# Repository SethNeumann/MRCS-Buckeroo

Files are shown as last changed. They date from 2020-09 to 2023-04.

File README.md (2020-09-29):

MRCS-Buckeroo

## License: Creative Commons Attribution-NonCommercial-ShareAlike

MRCS-Buckeroo

Model Railroad projects often require one or more power supplies for lighting and electronics powered from an 
auxilliary powr bus, usually 12VDC or a local "wall wart" power supply.  Commercial bucking supplies based on
LM 2596 or boosters based on XL6009 offere an inexpensive basis for developing any voltage from 3-35 volts with 
an input of 3-25 volts by choosing and adjusting an appropriate module.  

The Buckeroo has a 2.1 x 5.5 mm barrel connector and a 3.5mm screw terminal for input and 12 x 0.100 terminals 
power and ground out.  You may also use it as a power distribution block for layout bus power or a wall wart 
without further conversion by omitting the converter and jumpering around its pads.

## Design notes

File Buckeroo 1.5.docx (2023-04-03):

“Buckeroo”

Revision 0.3 02/17/2023

Seth Neumann, seth@modelrailroadcontrolsystems.com

Introduction

This document describes the Buckeroo power distribution board and how to assemble and install it.

Revision History

V0.1 – first pass – December 6, 2020

V 0.2 – adjusted connector designations, fixed typos December 7, 2020

V 0.3 – cover updates in rev 1.3-1.5

Table of Contents

Table of Figures

Table of Tables

# 1 Introduction

We often need to distribute power and ground for various devices under the layout and various power distribution boards have been offered over the years. This one fits our standard 7CM Tyco track (“Din Rail”) but can also be mounted using #6 screws and standoffs.

The Buckeroo provides connectors to distribute up to 12 pairs of positive voltage and ground. Pads are provided for a bucking or boosting converter to develop any voltage from about 3 - 30 volts. We assume you are running a 12V auxiliary power bus around your layout for switch machines, control panels and miscellaneous animations. The buckeroo is an easy way to derive other voltages (usually 5 or 3.3) as needed without having to run long busses from centralized power supplies with resultant I2R losses.

This revision (February 2023) supports pads for 2 more bucker and buck/boost converter footprints. As time goes on we will release further versions to support the then-available converter modules. Additionally, pads are provided for a simple linear regulator using TO-220 footprint regulators in the 78xx series, for those who prefer linear regulators.

Features:

- Takes power from either a 2.1 mm barrel jack or a 3.5mm two position screw terminal (I use this to take power from my 12 volt auxiliary bus and break it out for clusters of devices under the layout at whatever DC voltage is required).
- Connector pads provide up to 12 connections on 0.100 centers for +V and -V (Ground.) If you are assembling your own board and need less connections, you can use connectors with fewer positions.
- Pads for an LM2596 bucking (down) converter or an XL6009E boost (up) converter.
- Pads for MH340 mini bucking converters
- Pads for 6009 based buck/boost converters
- Pads for LM78xx regulators and associated capacitors
- Pads for 0.100 jumpers to be used if no buck or boost is required (distribution from layout aux power bus or from a wall wart of appropriate voltage).
- All components are through-hole technology for ease of assembly and repair.

Output connection pads and converter bypass jumpers are on 0.100” centers. This provides for a wide range of interconnect options and components. Connection options include screw terminal blocks, header pin connectors (male and female), right angle headers, and direct soldered wires.

Schematic, circuit board layouts and CAD files are available on the product page on our website and on my GitHub page https://github.com/SethNeumann.

# 2 Identification and Information

## 2.1. Board Layout

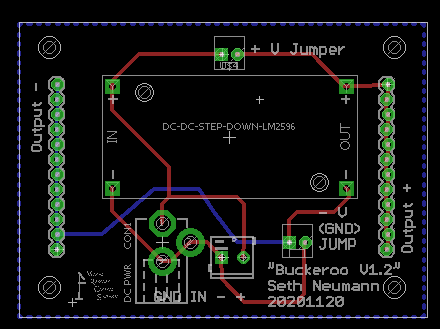
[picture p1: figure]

Figure 1 - Rev 1.2 Board Layout

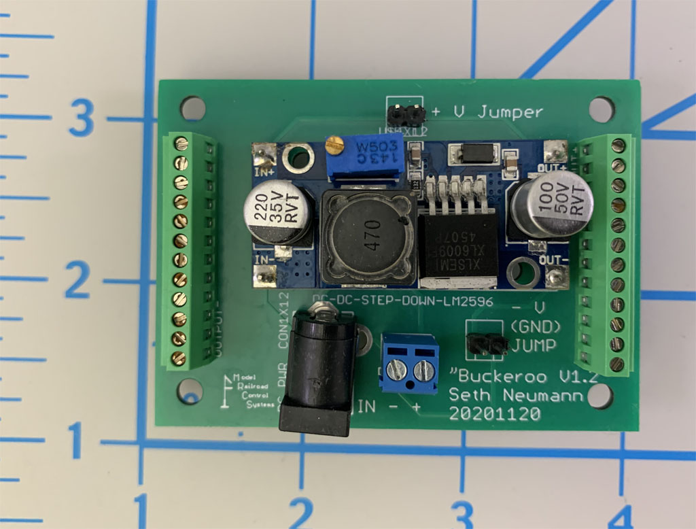
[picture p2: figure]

Figure 2 – Rev 1.2 Board (with boost converter) Top View

This board is sold as a single unit, assembled, and tested or as bare board, panel of 2. If you are interested in alternate connectors, alternate converters, large quantities, or custom modifications please contact us at sales@modelrailroadcontrolsystems.com

## 2.2. Bill of Materials

Table 1- Bill of Materials Rev 1.1

[update with various configurations and current prices]

Note these costs are correct as of December 2020 but will change over time. I’ve given Jameco (www.jameco.com) part numbers and prices where available and used Amazon, eBay and various Asian suppliers. These prices are for 10s which is lowest quantity that’s economical. For the bypass pins (CON3, CON4) I use 0.100 male headers. These can be purchased at about $0.01 per pin in breakaway strips of 40. Search the suppliers above and buy a pack of 10, which should keep you supplied for a few projects. Your cost per buckeroo (obviously you will have at least 2 as the board is a panel of 2) will vary from about $4.00 for a straight distribution block to $6.00 with a boost converter, depending on how you buy.

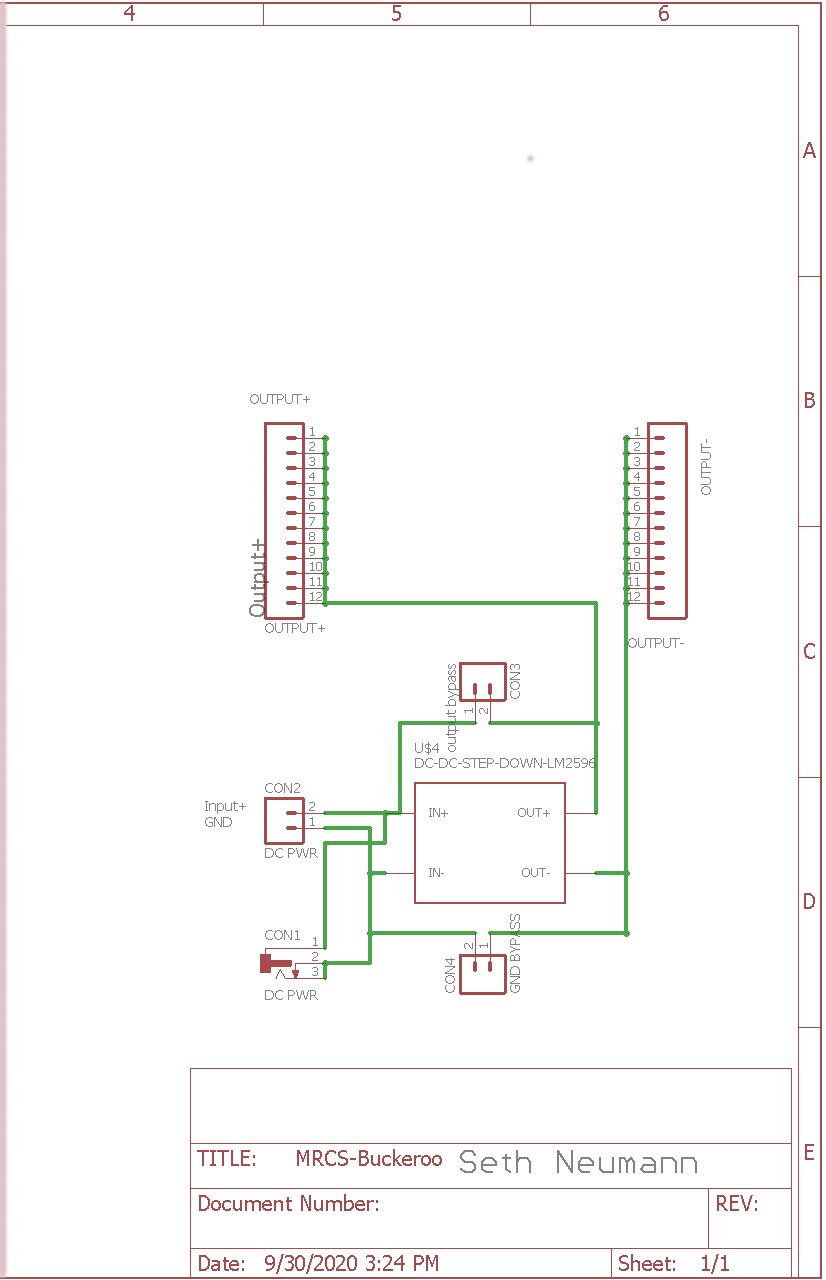
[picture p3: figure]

Figure 3 - Rev 1.2 Schematic

# 3 Options

## 3.1. Connectors

- The distribution and bypass connectors are on 0.100 centers (staggered slightly to hold the connectors in place during assembly). While our standard connector is the 0.100 screw terminal, you may substitute any 0.100 connector you prefer. If you are ordering an assembled and tested unit from MRCS and you would prefer a different connector, please contact us at sales@modelrailroadcontrolsystems.com and indicate your preference and we’ll provide a quotation.
- The Buckeroo has input pads for both a 2.1 mm barrel connector (usually used with a wall wart type power supply) and a 2 position 3.5mm screw terminal block. Either one or both may be used (for example if you want to daisy chain two Buckeroos together to get more outputs or two provide 2 voltages – one converter per Buckie).
- If you are using a buck or boost converter, you don’t need the bypass jumpers and may omit them. Both the buck and boost converters have an internal connection between their INPUT- and OUTPUT – terminals.
- If you are looking to save a few cents, solder jumpers of 22 Ga wire in place of the bypass jumpers (if used) and only equip the number of output screw terminals required. The 0.100 screw terminals cost ~$0.10 per terminal and are available in 2,3,4,6,8 and 12 pin configurations. If you only have (say) 4 devices needing power, you don’t need to stuff all 12 outputs.

## 3.2. Alternate Buck and boost converters

- MH340. This is a small converter, good for w.ww watts and suitable for small loads (perhaps you need ao supply 1,5 V for a vintage structure with grain of wheat bulbs).
- NNNN buck boost converter. Takes 12V in and produces from 3.3 to 33 volts out. Note that these are not well protected against setting the output voltage too high so use care in setting the high end of output volts. The failure mode is the board stops working, it does NOT short the input to the output.
- LM78xx linear regulators. Use the appropriate regulator (ex: 7805 produces 5V). Pads are provided for typical values of input and output filter capacitors (can also be added for straight distribution boards to decouple local loads). This design mounts the device vertically and relies on its integrated heat sink (bare metal tab) but you can add a heat sink for additional capacity. If these devices get to warm they “fold back” and drop the output votage/current to protect themselves.
- Most of these modules are 3 terminal devices (that is input, output and common ground) but 4 terminal (isolated input and output negative) are out there and some of the documentation isn’t the best, so check and set the bypass jumpers accordingly.

[insert table here]

Regulator | Input V | Output Voltage | Output Current | Watts
2596 | 12
6009 boost | 12
6009 buck/boost | 12 | 5
6009 buck/boost | 12 | 24
LM7809 | 12 | 9
LM7805 | 12 | 5

# 4 Assembly

All of the components are through-hole technology with wire leads. The general rule is install the lowest components first, working towards components that are higher off the board. This enables you to support the low components as you solder them. The suggested order assumes you are using both input connectors, screw terminals for the outputs and male headers for the bypass jumpers. If you choose to use different connectors, check the heights, and vary the build order accordingly.

[ ] Male Headers

[ ] install the bypass jumpers, CON3, CON4, if used. Hint – use a spare board as a jig to hold them in place as you solder

[ ] If using a buck/boost converter, break off 4 header pins and solder them onto the bottom of the IN-, IN+, OUT- and OUT+ holes with the long side down. Use a bare board as jig. Solder from the top. You could also use pin and socket combinations or bare wire

[ ] Screw Terminals

[ ] Install the OUTPUT- and OUTPUT+ screw terminals. . If you need less than 12 connections, feel free to use a screw terminal with fewer positions. These are available in many sizes from 2 to 12 positions

[ ] Install the 3.5mm input connector (if used)

[ ] Small ceramic filter caps, if used

Install after the screw terminals as you should leave about 1/32” of lead above the board to avoid breaking the leads internally

[ ] Barrel Jack

[ ] Install the barrel jack, if used

[ ] Electrolytic filter capacitor, if used

These usually stad up about 10-15 mm, compare with barrel jack to determine sequence

[ ] Install the Buck/Boost converter, if used. I used 0.100 header pins for the input and output pins in the corners. You could also use pin and socket combinations or bare wire.

[ ] slip the “Berg Jumpers” onto the bypass pins CON3, CON4 if not using a converter or regulator.

# 5 Testing

Testing your Buckeroo is quick and simple:

1. Using a voltmeter set to resistance (or continuity if has a beeper) put one lead on the input screw terminal – and check for continuity with the -V bypass jumper, do the same with + and the +V jumper.
2. Check from the other side of the bypass jumper to each of the screw terminals in use. I find I sometimes miss a pad when soldering these.
3. If not using a bucker/booster, connect your input voltage and install the jumpers and check that you see the same voltage on the outputs
4. If using a bucker/booster or a regulator, apply power to the input and connect your meter across OUTPUT + and OUTPUT - (clip leads will be handy). Adjust the output voltage to your desired voltage by turning the small screw on blue pot counterclockwise. It’s a 20-turn pot, so it may take a while to see anything happen.

# 6 Installation and Connections

## 6.1 Power Connections

Note that 24 Ga wire can handle up to 0.6A (600 mA). So, the total current delivered over any conductor should not exceed 600 mA. Also note that the bucking converter can only source 3A, and since most of us buy these from inexpensive suppliers on major commerce and auction sites, it is wise to allow a little margin of safety.

If in doubt, contact us! sales@modelrailroadcontrolsystem.com

Page 2 www.modelrailroadcontrolsystems.com December 7, 2020

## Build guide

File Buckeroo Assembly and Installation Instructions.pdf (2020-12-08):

# “Buckeroo”

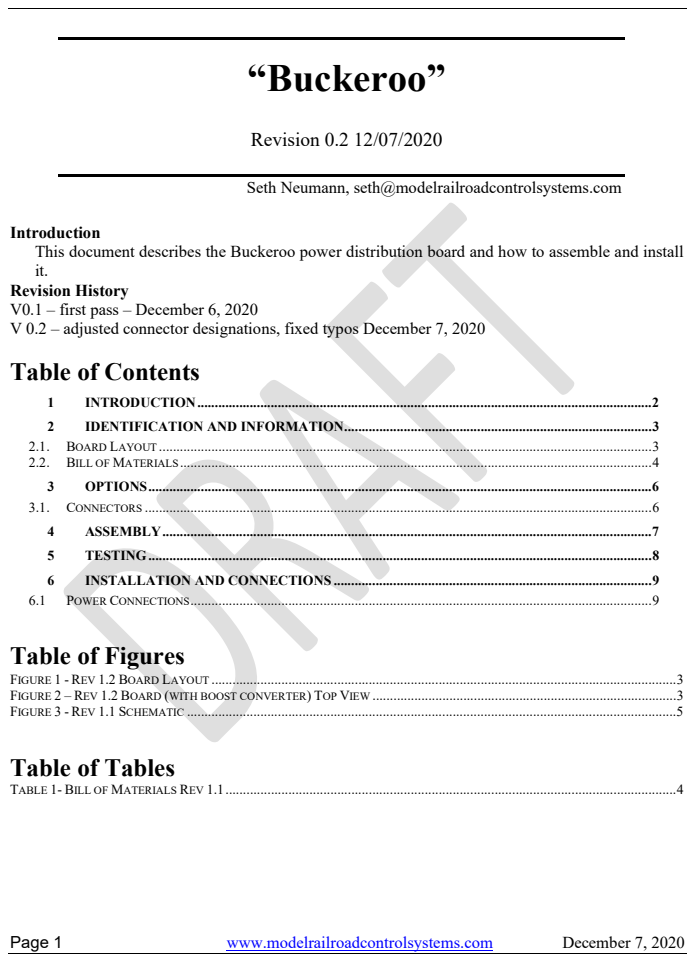
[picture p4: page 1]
Page 1; www.modelrailroadcontrolsystems.com; December 7, 2020; Revision 0.2 12/07/2020

Seth Neumann, seth@modelrailroadcontrolsystems.com

Introduction
This document describes the Buckeroo power distribution board and how to assemble and install
Revision History
V0.1 – first pass – December 6, 2020
V 0.2 – adjusted connector designations, fixed typos December 7, 2020
Table of Contents

1 INTRODUCTION .................................................................................................................................. 2
2 IDENTIFICATION AND INFORMATION ........................................................................................ 3
2.1. BOARD LAYOUT ............................................................................................................................................. 3
2.2. BILL OF MATERIALS ....................................................................................................................................... 4
3 OPTIONS ................................................................................................................................................ 6
3.1. CONNECTORS ................................................................................................................................................. 6
4 ASSEMBLY ............................................................................................................................................ 7
5 TESTING ................................................................................................................................................ 8
6 INSTALLATION AND CONNECTIONS ........................................................................................... 9
6.1 POWER CONNECTIONS .................................................................................................................................... 9
Table of Figures

FIGURE 1 - REV 1.2 BOARD LAYOUT ..................................................................................................................................... 3
FIGURE 2 – REV 1.2 BOARD (WITH BOOST CONVERTER) TOP VIEW ....................................................................................... 3
FIGURE 3 - REV 1.1 SCHEMATIC ............................................................................................................................................ 5
Table of Tables
TABLE 1- BILL OF MATERIALS REV 1.1 ................................................................................................................................. 4

Page 2 | www.modelrailroadcontrolsystems.com | December 7, 2020

### 1 INTRODUCTION

The Buckeroo provides connectors to distribute up to 12 pairs of positive voltage and ground. Pads are provided for a bucking or boosting converter to develop any voltage from about 3 - 30 volts.

We often need to distribute power and ground for various devices under the layout and various power distribution boards have been offered over the years. This one fits our standard 7CM Tyco track (“Din Rail”) but can also be mounted using #6 screws and standoffs.

Features:

- Takes power from either a 2.1 mm barrel jack or a 3.5mm two position screw terminal (I use this to take power from my 12 volt auxiliary bus and break it out for clusters of devices under the layout at whatever DC voltage is required).
- Connector pads provide up to 12 connections on 0.100 centers for +V and -V (Ground.) If you are assembling your own board and need less connections, you can use connectors with fewer positions.
- Pads for an LM2596 bucking (down) converter or an XL6009E boost (up) converter.
- Pads for 0.100 jumpers to be used if no buck or boost is required (distribution from layout aux power bus or from a wall wart of appropriate voltage).
- All components are through-hole technology for ease of assembly and repair.

Output connection pads and converter bypass jumpers are on 0.100” centers. This provides for a wide range of interconnect options and components. Connection options include screw terminal blocks, header pin connectors (male and female), right angle headers, and direct soldered wires.

Schematic, circuit board layouts and CAD files are available on the product page on our website and on my GitHub page https://github.com/SethNeumann.

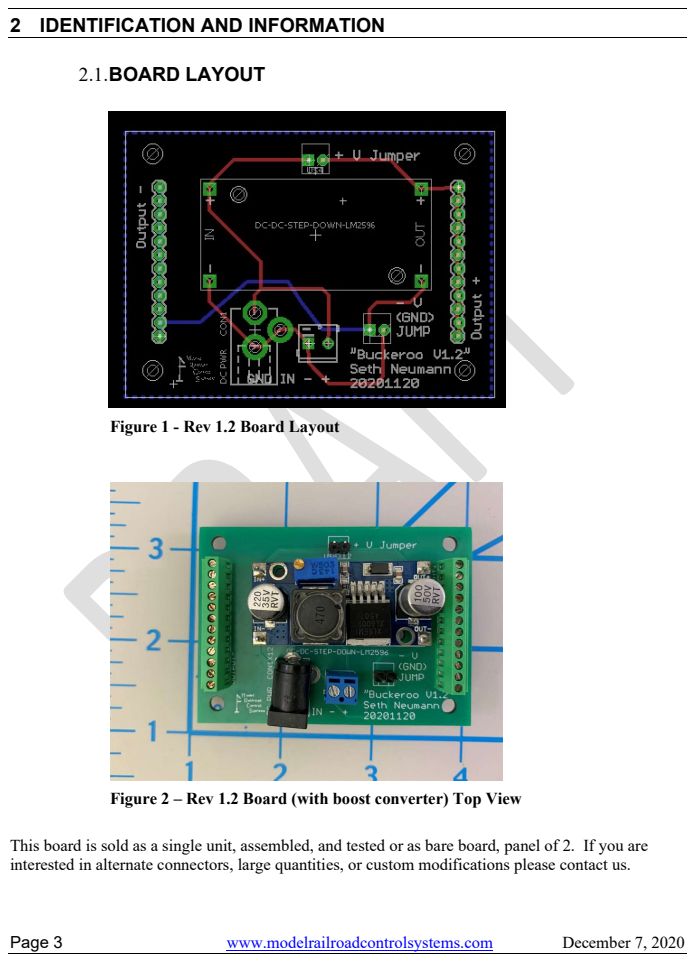
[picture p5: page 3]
Page 3; www.modelrailroadcontrolsystems.com; December 7, 2020; 2.1.BOARD LAYOUT

2 IDENTIFICATION AND INFORMATION

Figure 1 - Rev 1.2 Board Layout

Figure 2 – Rev 1.2 Board (with boost converter) Top View

This board is sold as a single unit, assembled, and tested or as bare board, panel of 2. If you are
interested in alternate connectors, large quantities, or custom modifications please contact us.

Page 4 | www.modelrailroadcontrolsystems.com | December 7, 2020

2.2.BILL OF MATERIALS

Qty | Value | Package | Parts | Description | Jameco | _1 | Asian/eBay/AMZNExtd
1 DC PWR | DCJ0202 | CON1 | DC POWER JACK | 101178 $ 0.50 $ | 0.08 $ 0.08
1 DC PWR | SCREWTERMINAL-3.5MM-2_LOCK | CON2 | PHOENIX CONNECTOR | 2094506 $ 0.35 | $ 0.35
1 DC-DC-STEP-DOWN-LM2596 | DC-DC-STEP-DOWN-LM2596 | U$4 | DC/DC Step-Down Regulator based on LM2596-ADJ chip | $ | 1.25 $ 1.25
1 DC-DC-STEP-STEP UP-XL6009 | DC-DC-STEP-DOWN-LM2596 | U$4 | DC/DC Step-Up Regulator based on XL6009 chip | $ | 2.00 $ 2.00
2 BYPASS | MOLEX-1X2_LOCK | CON3, CON4 | PHOENIX CONNECTOR | $ | 0.01 $ 0.02
2 OUTPUT+ | 1X12_LOCK | OUTPUT+, OUTPUT - Screw Terminal | $ | 0.80 $ 1.60
2 | 1x2 | Berg jumper for bypass | 19141 | $ | 0.13 $ 0.26
1 Printed Circuit Board | $ | 2.50 | $2.50

Table 1- Bill of Materials Rev 1.1

Note these costs are correct as of December 2020 but may change over time. I’ve given Jameco (www.jameco.com) part numbers and prices where available and used Amazon, eBay and various Asian suppliers. These prices are for 10s which is lowest quantity that’s economical. For the bypass pins (CON3, CON4) I use 0.100 male headers. These can be purchased at about $0.01 per pin in breakaway strips of 40. Search the suppliers above and buy a pack of 10, which should keep you for a few projects. Your cost per buckeroo (obviously you will have at least 2 as the board is a panel of 2) will vary from about $4.00 for a straight distribution block to $6.00 with a boost converter, depending on how you buy.

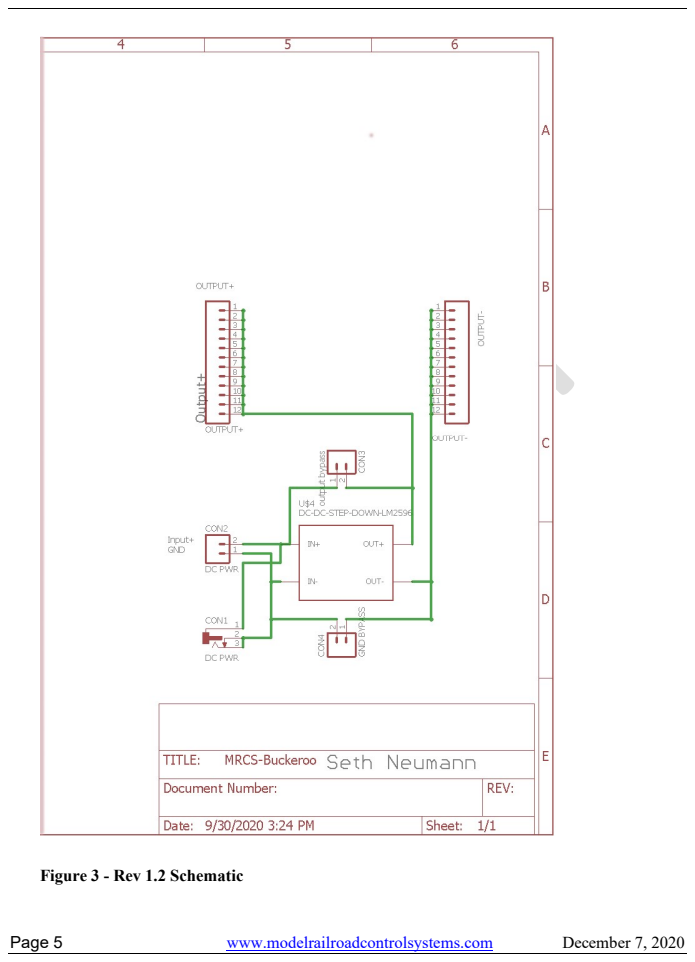
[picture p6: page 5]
Page 5; www.modelrailroadcontrolsystems.com; December 7, 2020

Figure 3 - Rev 1.2 Schematic

Page 6 | www.modelrailroadcontrolsystems.com | December 7, 2020

### 3 OPTIONS

3.1.CONNECTORS

- The distribution and bypass connectors are on 0.100 centers (staggered slightly to hold the connectors in place during assembly). While our standard connector is the 0.100 screw terminal, you may substitute any 0.100 connector you prefer. If you are ordering an assembled and tested unit from MRCS and you would prefer a different connector, please contact us at sales@modelrailroadcontrolsystems.com and indicate your preference and we’ll provide a quotation.
- The Buckeroo has input pads for both a 2.1 mm barrel connector (usually used with a wall wart type power supply) and a 2 position 3.5mm screw terminal block. Either one or both may be used (for example if you want to daisy chain two Buckeroos together to get more outputs or two provide 2 voltages – one converter per Buckie).
- If you are using a buck or boost converter, you don’t need the bypass jumpers and may omit them. Both the buck and boost converters have an internal connection between their INPUT-and OUTPUT – terminals.
- If you are looking to save a few cents, solder jumpers of 22 Ga wire in place of the bypass jumpers (if used) and only equip the number of output screw terminals required. The 0.100 screw terminals cost ~$0.10 per terminal and are available in 2,3,4,6,8 and 12 pin configurations. If you only have (say) 4 devices needing power, you don’t need to stuff all 12 outputs.

Page 7 | www.modelrailroadcontrolsystems.com | December 7, 2020

### 4 ASSEMBLY

All of the components are through-hole technology with wire leads. The general rule is installing the lowest components first, working towards components that are higher off the board. This enables you to support the low components as you solder them. The suggested order assumes you are using both input connectors, screw terminals for the outputs and male headers for the bypass jumpers. If you choose to use different connectors, check the heights, and vary the build order accordingly.

[ ] Male Headers

[ ] install the bypass jumpers, CON3, CON4, if used. Hint – use a spare board as a jig to hold them in place as you solder
[ ] If using a buck/boost converter, break off 4 header pins and solder them onto the bottom of the IN-, IN+, OUT- and OUT+ holes with the long side down. Use a bare board as jig. Solder from the top. You could also use pin and socket combinations or bare wire

[ ] Screw Terminals
[ ] Install the OUTPUT- and OUTPUT+ screw terminals. . If you need less than 12 connections, feel free to use a screw terminal with fewer positions. These are available in many sizes from 2 to 12 positions
[ ] Install the 3.5mm input connector (if used)

[ ] Barrel Jack
[ ] Install the barrel jack, if used

[ ] Install the Buck/Boost converter, if used. I used 0.100 header pins for the input and output pins in the corners. You could also use pin and socket combinations or bare wire.

[ ] slip the “Berg Jumpers” onto the bypass pins CON3, CON4 if not using a bucker or booster.

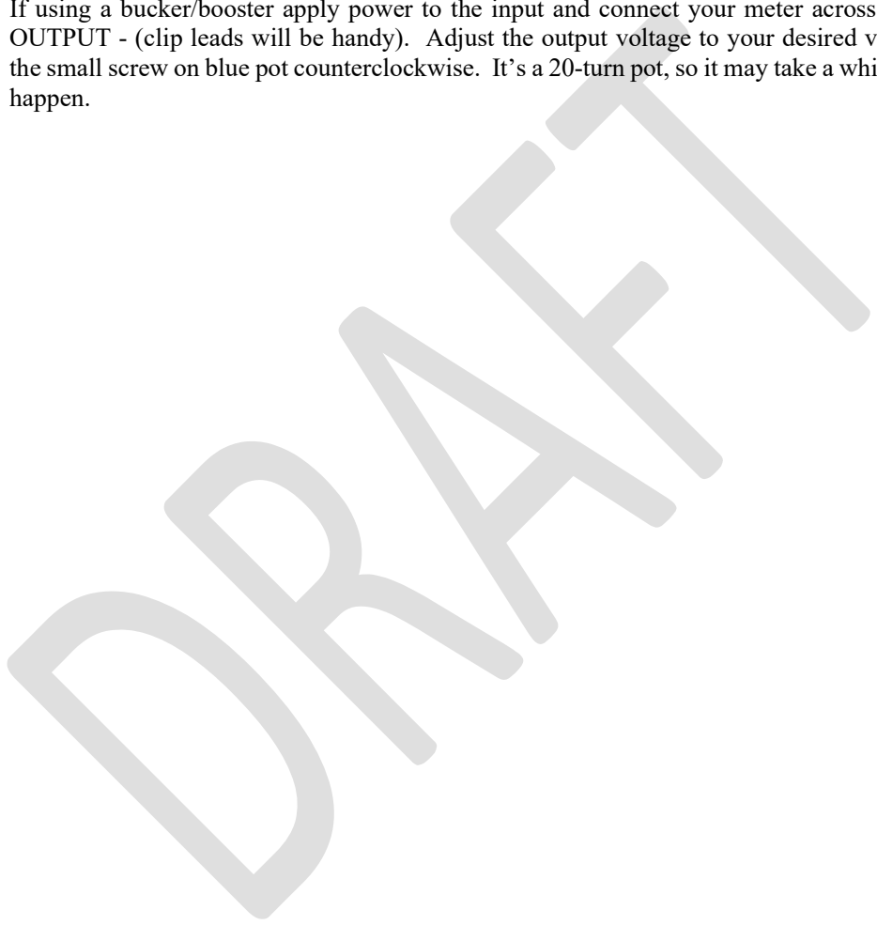
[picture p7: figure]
happen.

Page 8 | www.modelrailroadcontrolsystems.com | December 7, 2020

### 5 TESTING

Testing your Buckeroo is quick and simple:
1. Using a voltmeter set to resistance (or continuity if has a beeper) put one lead on the input screw terminal – and check for continuity with the -V bypass jumper, do the same with + and the +V jumper.
2. Check from the other side of the bypass jumper to each of the screw terminals in use. I find I sometimes miss a pad when soldering these.
3. If not using a bucker/booster, connect your input voltage and install the jumpers and check that you see the same voltage on the outputs
4. If using a bucker/booster apply power to the input and connect your meter across OUTPUT + and OUTPUT - (clip leads will be handy). Adjust the output voltage to your desired voltage by turning the small screw on blue pot counterclockwise. It’s a 20-turn pot, so it may take a while to see anything

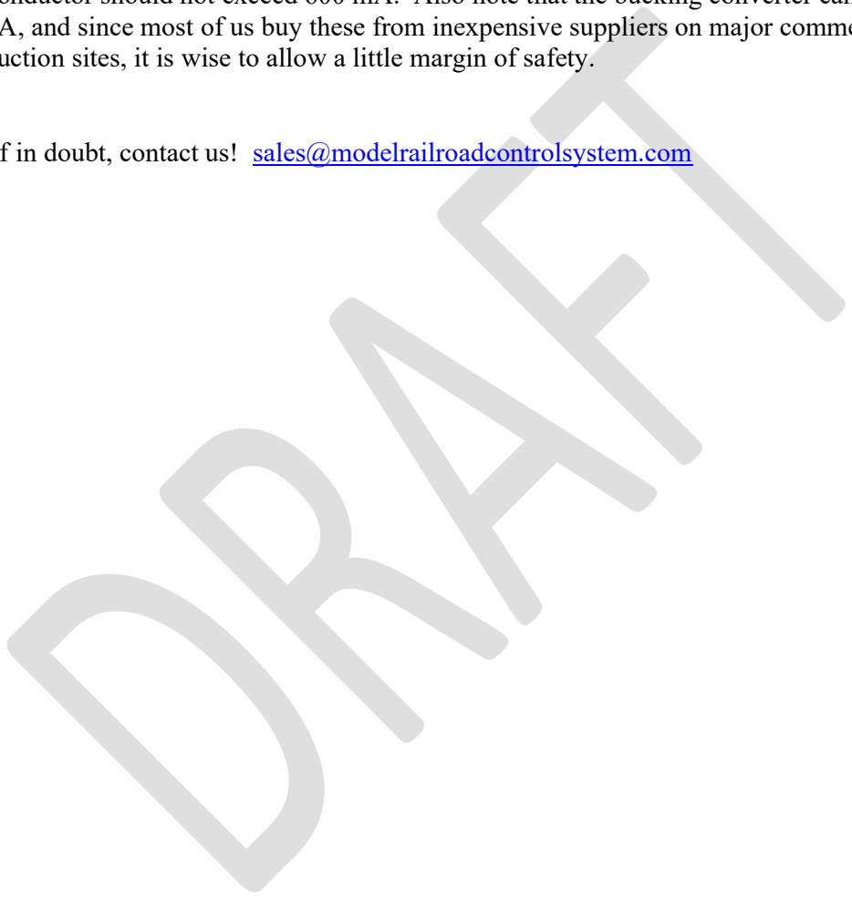
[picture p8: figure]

Page 9 | www.modelrailroadcontrolsystems.com | December 7, 2020

### 6 INSTALLATION AND CONNECTIONS

### 6.1 POWER CONNECTIONS

Note that 24 Ga wire can handle up to 0.6A (600 mA). So, the total current delivered over any conductor should not exceed 600 mA. Also note that the bucking converter can only source 3A, and since most of us buy these from inexpensive suppliers on major commerce and auction sites, it is wise to allow a little margin of safety.

If in doubt, contact us! sales@modelrailroadcontrolsystem.com

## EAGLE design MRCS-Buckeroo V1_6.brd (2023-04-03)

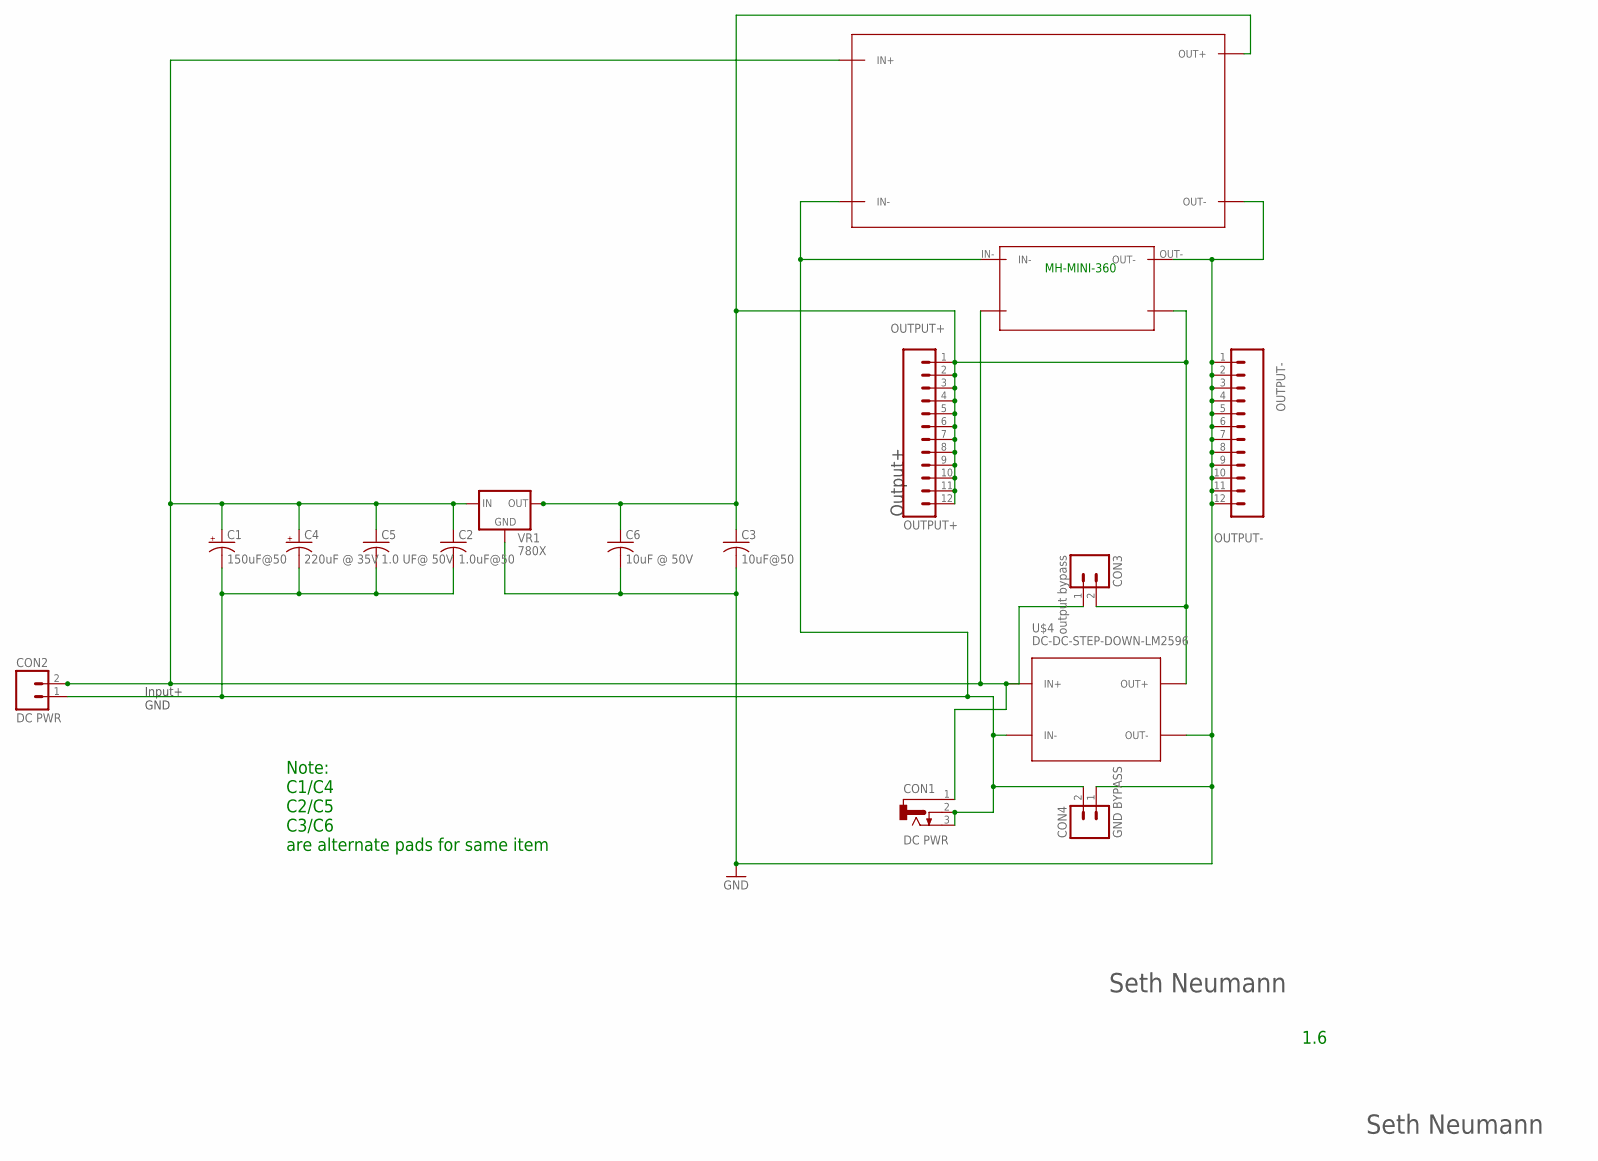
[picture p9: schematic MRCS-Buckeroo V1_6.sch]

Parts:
C1: 150uF@50; E5-10.5
C2: 1.0uF@50; C-PTH-0.100
C3: 10uF@50; C-PTH-0.100
C4: 220uF @ 35V; E2.5-6
C5: 1.0 UF@ 50V; C050-024X044
C6: 10uF @ 50V; C050-024X044
CON1: DC PWR; DCJ0202
CON2: DC PWR; SCREWTERMINAL-3.5MM-2_LOCK
CON3: output bypass; MOLEX-1X2_LOCK
CON4: GND BYPASS; MOLEX-1X2_LOCK
MH-MINI-360: MH-MINI-360
OUTPUT+: OUTPUT+; 1X12_LOCK
OUTPUT-: OUTPUT-; 1X12_LOCK
U$4: DC-DC-STEP-DOWN-LM2596
U$5: XL6009BOARD; XL6009_BOARD
VR1: 780X; TO-220-RA

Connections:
GND: C1.-, C2.2, C3.2, C4.-, C5.2, C6.2, CON1.2, CON1.3, CON2.1 (A), CON4.1 (A), CON4.2 (B), MH-MINI-360.IN-, MH-MINI-360.OUT-, OUTPUT-.1, OUTPUT-.2, OUTPUT-.3, OUTPUT-.4, OUTPUT-.5, OUTPUT-.6, OUTPUT-.7, OUTPUT-.8, OUTPUT-.9, OUTPUT-.10, OUTPUT-.11, OUTPUT-.12, U$4.IN-, U$4.OUT-, U$5.IN-, U$5.OUT-, VR1.GND
INPUT+: C1.+, C2.1, C4.+, C5.1, CON1.1, CON2.2 (B), CON3.1 (A), MH-MINI-360.INN+, U$4.IN+, U$5.IN+, VR1.IN
OUTPUT+: C3.1, C6.1, CON3.2 (B), MH-MINI-360.OUTT+, OUTPUT+.1, OUTPUT+.2, OUTPUT+.3, OUTPUT+.4, OUTPUT+.5, OUTPUT+.6, OUTPUT+.7, OUTPUT+.8, OUTPUT+.9, OUTPUT+.10, OUTPUT+.11, OUTPUT+.12, U$4.OUT+, U$5.OUT+, VR1.OUT

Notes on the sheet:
Output+
Input+ GND
Seth Neumann
MH-MINI-360
1.6
Note: C1/C4 C2/C5 C3/C6 are alternate pads for same item

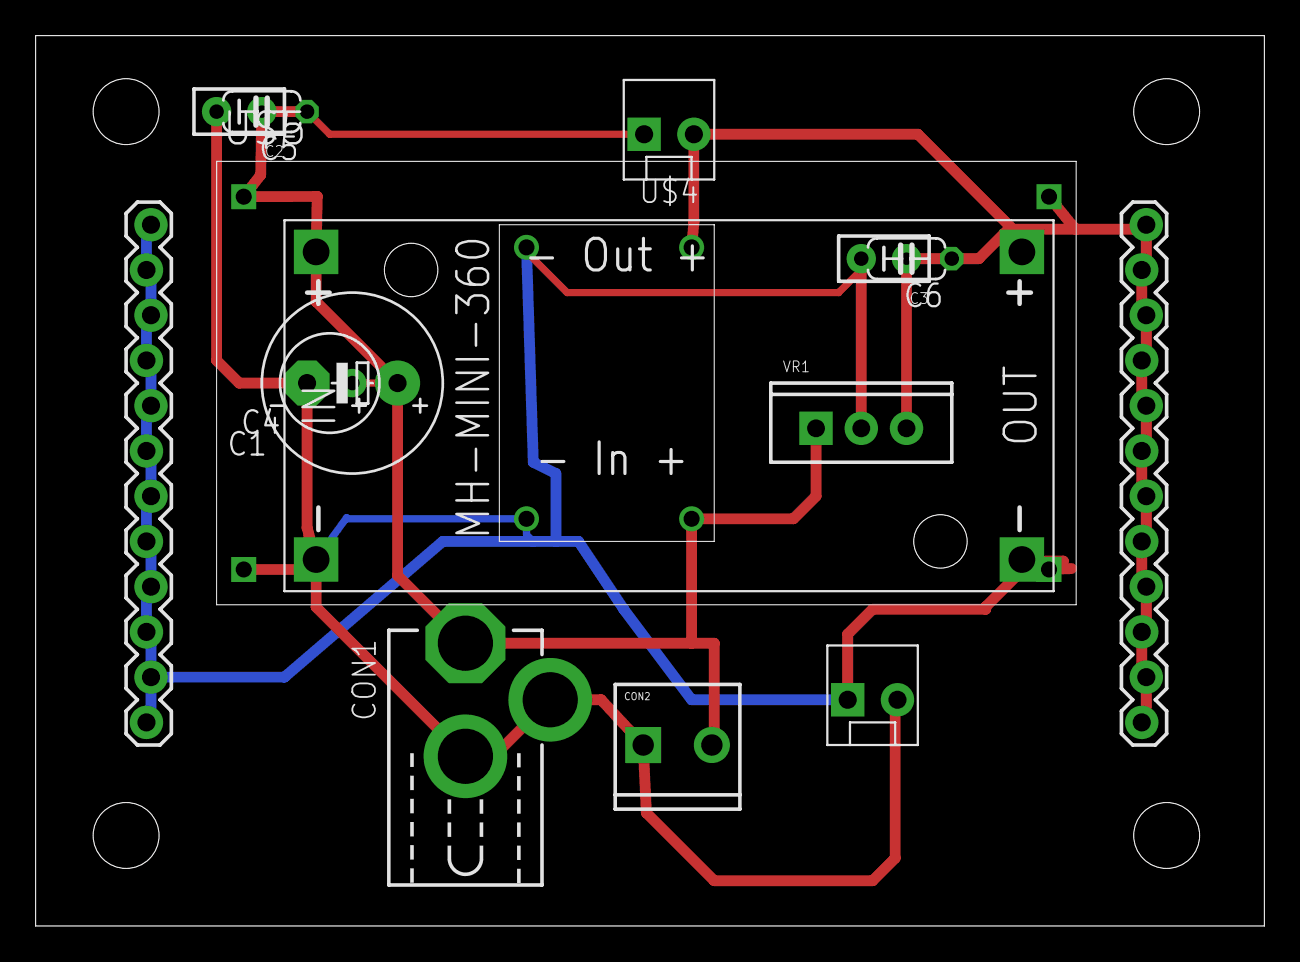
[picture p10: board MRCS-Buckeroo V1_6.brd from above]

Board: 2 copper layers, 69.0 x 50.0 mm, 19 parts (0 on the bottom side), 3 nets.

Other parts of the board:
U$1: CA-PROP65WARNING
U$2: MRCSLOGOTOP
U$3: MRCSLOGOBTM

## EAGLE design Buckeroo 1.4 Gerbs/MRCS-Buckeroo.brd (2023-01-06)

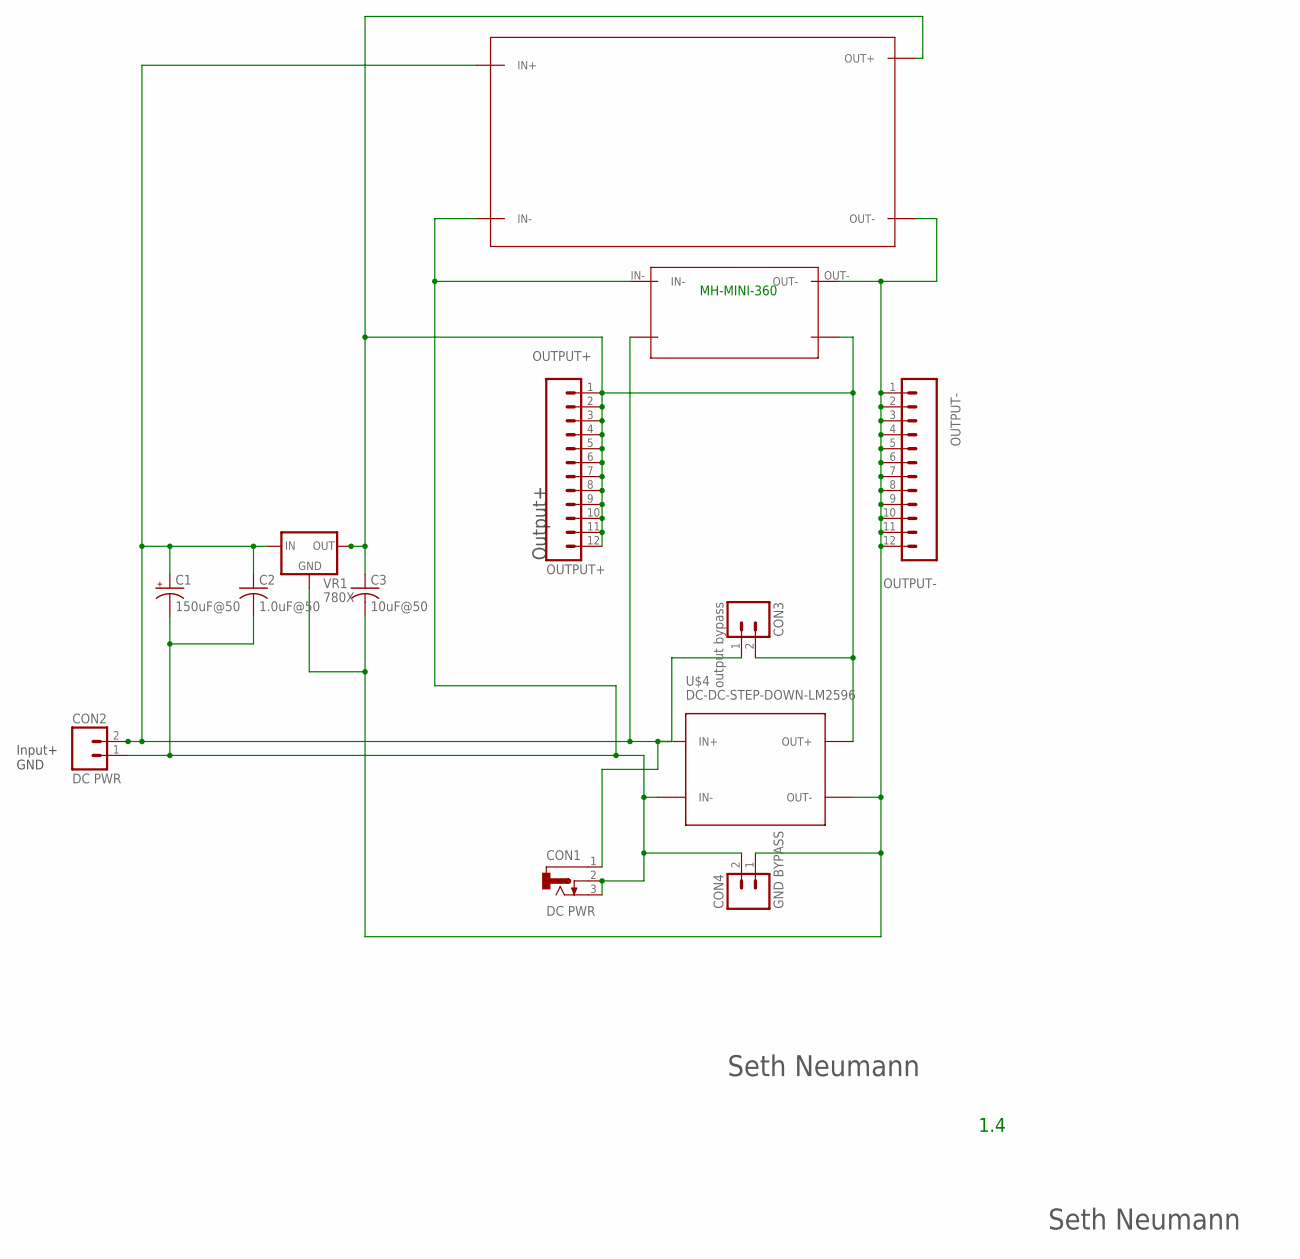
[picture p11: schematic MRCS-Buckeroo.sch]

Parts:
C1: 150uF@50; E5-10.5
C2: 1.0uF@50; C-PTH-0.100
C3: 10uF@50; C-PTH-0.100
CON1: DC PWR; DCJ0202
CON2: DC PWR; SCREWTERMINAL-3.5MM-2_LOCK
CON3: output bypass; MOLEX-1X2_LOCK
CON4: GND BYPASS; MOLEX-1X2_LOCK
MH-MINI-360: MH-MINI-360
OUTPUT+: OUTPUT+; 1X12_LOCK
OUTPUT-: OUTPUT-; 1X12_LOCK
U$4: DC-DC-STEP-DOWN-LM2596
U$5: XL6009BOARD; XL6009_BOARD
VR1: 780X; TO-220-RA

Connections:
GND: C1.-, C2.2, CON1.2, CON1.3, CON2.1 (A), CON4.2 (B), MH-MINI-360.IN-, U$4.IN-, U$5.IN-
INPUT+: C1.+, C2.1, CON1.1, CON2.2 (B), CON3.1 (A), MH-MINI-360.INN+, U$4.IN+, U$5.IN+, VR1.IN
OUTPUT+: C3.1, CON3.2 (B), MH-MINI-360.OUTT+, OUTPUT+.1, OUTPUT+.2, OUTPUT+.3, OUTPUT+.4, OUTPUT+.5, OUTPUT+.6, OUTPUT+.7, OUTPUT+.8, OUTPUT+.9, OUTPUT+.10, OUTPUT+.11, OUTPUT+.12, U$4.OUT+, U$5.OUT+, VR1.OUT
OUTPUT-: C3.2, CON4.1 (A), MH-MINI-360.OUT-, OUTPUT-.1, OUTPUT-.2, OUTPUT-.3, OUTPUT-.4, OUTPUT-.5, OUTPUT-.6, OUTPUT-.7, OUTPUT-.8, OUTPUT-.9, OUTPUT-.10, OUTPUT-.11, OUTPUT-.12, U$4.OUT-, U$5.OUT-, VR1.GND

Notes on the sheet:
Output+
Input+ GND
Seth Neumann
MH-MINI-360
1.4

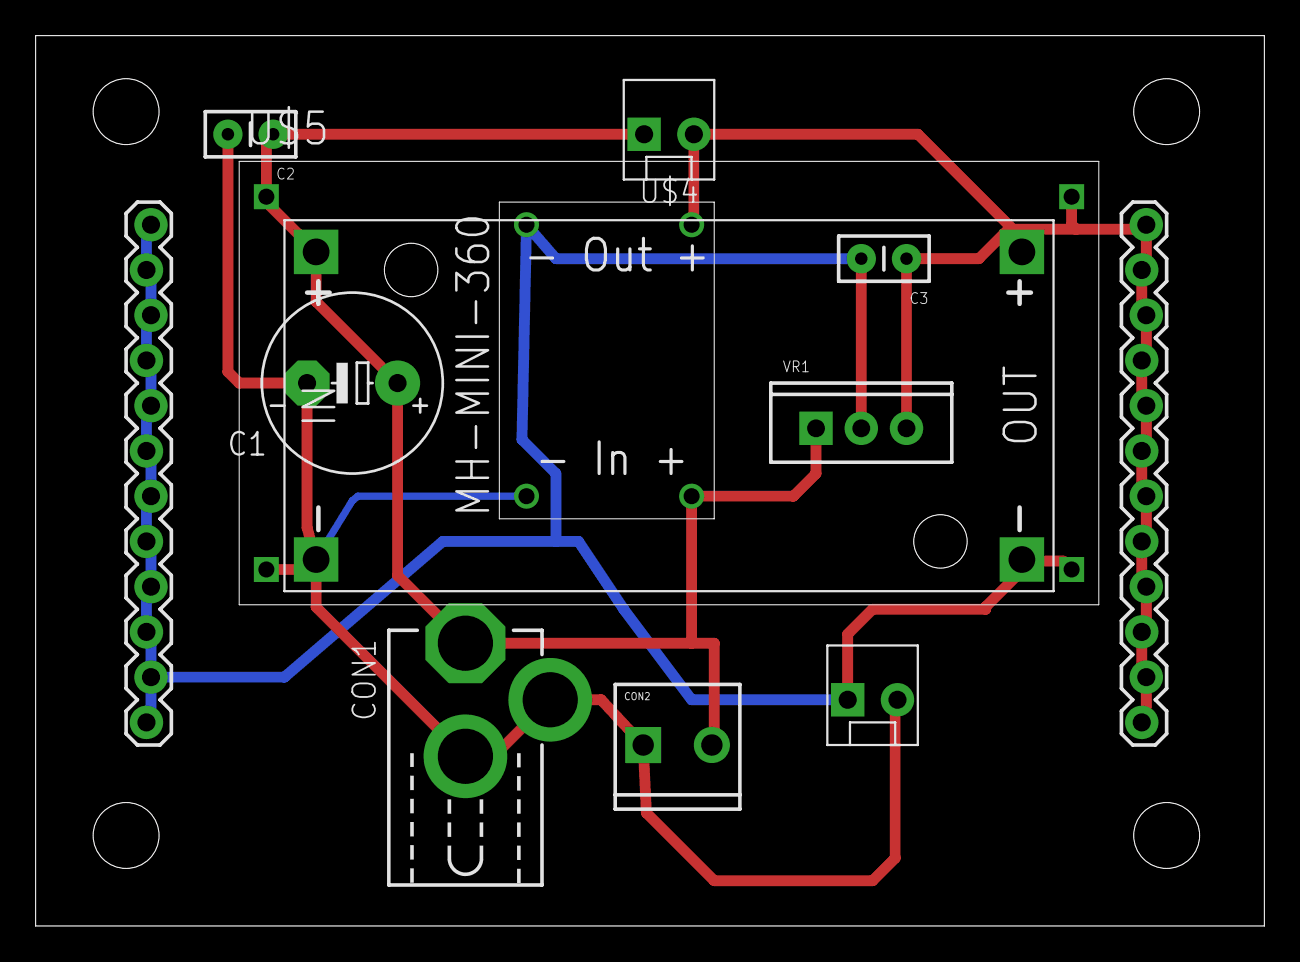
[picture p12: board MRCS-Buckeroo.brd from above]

Board: 2 copper layers, 69.0 x 50.0 mm, 16 parts (0 on the bottom side), 4 nets.

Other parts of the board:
U$1: CA-PROP65WARNING
U$2: MRCSLOGOTOP
U$3: MRCSLOGOBTM

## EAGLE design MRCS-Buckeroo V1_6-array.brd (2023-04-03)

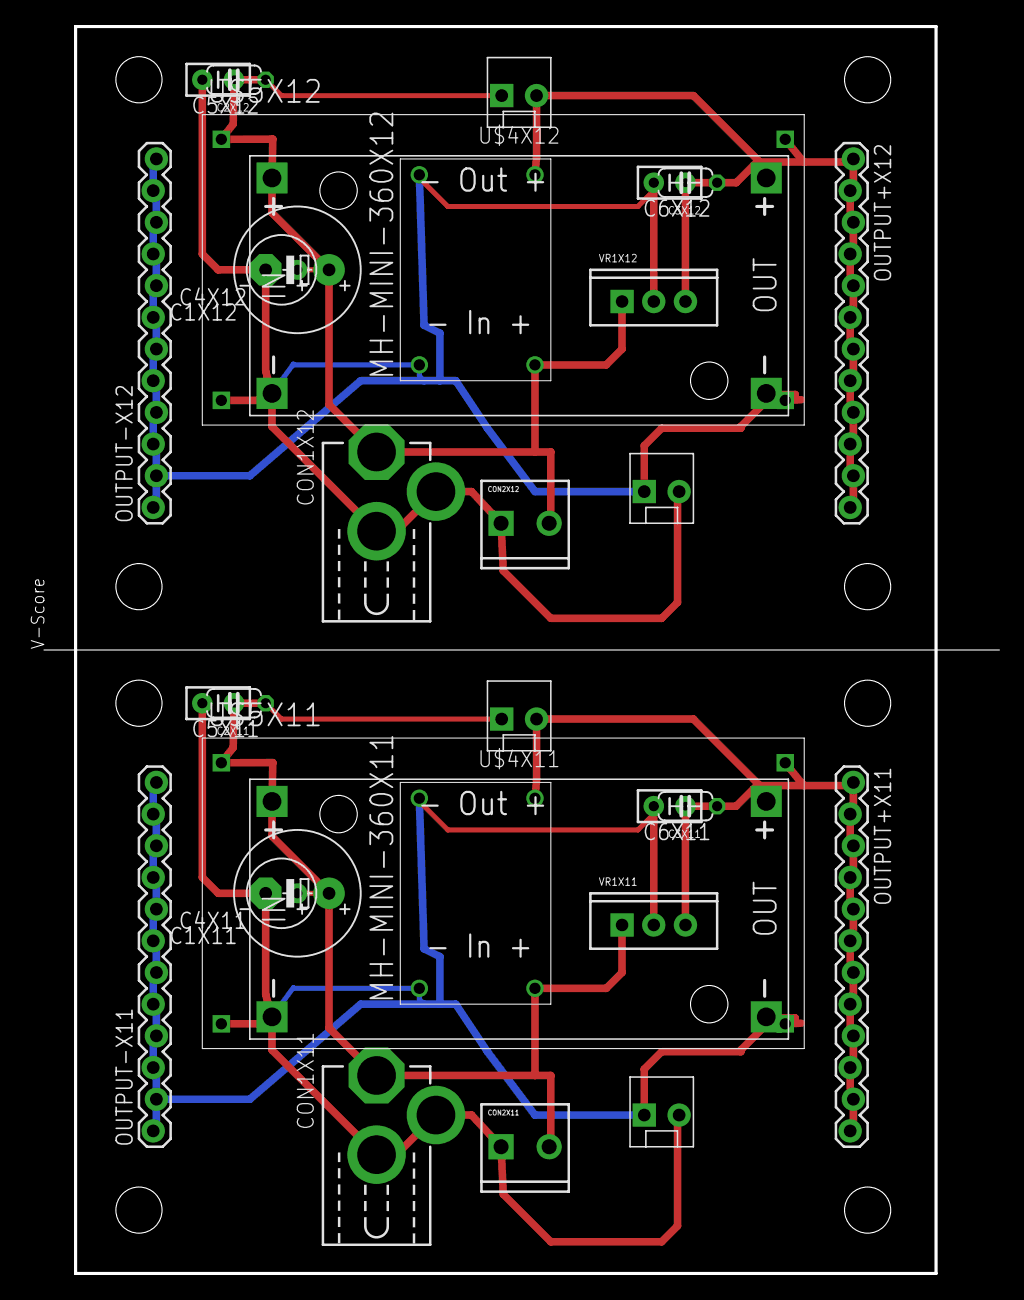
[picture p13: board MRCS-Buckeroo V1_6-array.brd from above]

Board: 2 copper layers, 69.0 x 100.0 mm, 38 parts (0 on the bottom side), 6 nets.

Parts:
C1X11, C1X12: 150uF@50; E5-10.5
C2X11, C2X12: 1.0uF@50; C-PTH-0.100
C3X11, C3X12: 10uF@50; C-PTH-0.100
C4X11, C4X12: 220uF @ 35V; E2.5-6
C5X11, C5X12: 1.0 UF@ 50V; C050-024X044
C6X11, C6X12: 10uF @ 50V; C050-024X044
CON1X11, CON1X12: DC PWR; DCJ0202
CON2X11, CON2X12: DC PWR; SCREWTERMINAL-3.5MM-2_LOCK
CON3X11, CON3X12: output bypass; MOLEX-1X2_LOCK
CON4X11, CON4X12: GND BYPASS; MOLEX-1X2_LOCK
MH-MINI-360X11, MH-MINI-360X12: MH-MINI-360
OUTPUT+X11, OUTPUT+X12: OUTPUT+; 1X12_LOCK
OUTPUT-X11, OUTPUT-X12: OUTPUT-; 1X12_LOCK
U$1X11, U$1X12: CA-PROP65WARNING
U$2X11, U$2X12: MRCSLOGOTOP
U$3X11, U$3X12: MRCSLOGOBTM
U$4X11, U$4X12: DC-DC-STEP-DOWN-LM2596
U$5X11, U$5X12: XL6009BOARD; XL6009_BOARD
VR1X11, VR1X12: 780X; TO-220-RA

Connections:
GNDX11: C1X11.-, C2X11.2, C3X11.2, C4X11.-, C5X11.2, C6X11.2, CON1X11.2, CON1X11.3, CON2X11.1, CON4X11.1, CON4X11.2, MH-MINI-360X11.IN-, MH-MINI-360X11.OUT-, OUTPUT-X11.1, OUTPUT-X11.2, OUTPUT-X11.3, OUTPUT-X11.4, OUTPUT-X11.5, OUTPUT-X11.6, OUTPUT-X11.7, OUTPUT-X11.8, OUTPUT-X11.9, OUTPUT-X11.10, OUTPUT-X11.11, OUTPUT-X11.12, U$4X11.IN-, U$4X11.OUT-, U$5X11.IN-, U$5X11.OUT-, VR1X11.GND
GNDX12: C1X12.-, C2X12.2, C3X12.2, C4X12.-, C5X12.2, C6X12.2, CON1X12.2, CON1X12.3, CON2X12.1, CON4X12.1, CON4X12.2, MH-MINI-360X12.IN-, MH-MINI-360X12.OUT-, OUTPUT-X12.1, OUTPUT-X12.2, OUTPUT-X12.3, OUTPUT-X12.4, OUTPUT-X12.5, OUTPUT-X12.6, OUTPUT-X12.7, OUTPUT-X12.8, OUTPUT-X12.9, OUTPUT-X12.10, OUTPUT-X12.11, OUTPUT-X12.12, U$4X12.IN-, U$4X12.OUT-, U$5X12.IN-, U$5X12.OUT-, VR1X12.GND
INPUT+X11: C1X11.+, C2X11.1, C4X11.+, C5X11.1, CON1X11.1, CON2X11.2, CON3X11.1, MH-MINI-360X11.INN+, U$4X11.IN+, U$5X11.IN+, VR1X11.IN
INPUT+X12: C1X12.+, C2X12.1, C4X12.+, C5X12.1, CON1X12.1, CON2X12.2, CON3X12.1, MH-MINI-360X12.INN+, U$4X12.IN+, U$5X12.IN+, VR1X12.IN
OUTPUT+X11: C3X11.1, C6X11.1, CON3X11.2, MH-MINI-360X11.OUTT+, OUTPUT+X11.1, OUTPUT+X11.2, OUTPUT+X11.3, OUTPUT+X11.4, OUTPUT+X11.5, OUTPUT+X11.6, OUTPUT+X11.7, OUTPUT+X11.8, OUTPUT+X11.9, OUTPUT+X11.10, OUTPUT+X11.11, OUTPUT+X11.12, U$4X11.OUT+, U$5X11.OUT+, VR1X11.OUT
OUTPUT+X12: C3X12.1, C6X12.1, CON3X12.2, MH-MINI-360X12.OUTT+, OUTPUT+X12.1, OUTPUT+X12.2, OUTPUT+X12.3, OUTPUT+X12.4, OUTPUT+X12.5, OUTPUT+X12.6, OUTPUT+X12.7, OUTPUT+X12.8, OUTPUT+X12.9, OUTPUT+X12.10, OUTPUT+X12.11, OUTPUT+X12.12, U$4X12.OUT+, U$5X12.OUT+, VR1X12.OUT

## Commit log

2020-09-29 initial coimmit
    initial commit
    [EagleTemplate-new.brd, EagleTemplate-new.sch, MRCS-Buckeroo.brd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]
2020-09-30 sent to fab
    sent to fab
    [MRCS-Buckeroo.brd, MRCS-Buckeroo.sch]
2020-12-08 Added 1st pass of documentation
    Assembly and Installation Instructions
    [MRCS-Buckeroo.brd]
2020-12-08 fixed connector designations
    fixed connector designations, corrected panel to 2
2020-12-08 fix error in scehmatic revision, BOM not displaying
    fix error in scehmatic revision, BOM not displaying
2022-11-14 Added regulator options
    Supports MH-Mini-360 bucking converter and 780X TO-220 linear regulators
    [MRCS-Buckeroo.brd, MRCS-Buckeroo.sch]
2023-01-06 Release 3 sent out for fab
    These include the mini bucker and an updown bucker as well as the pads for 780X TO220 packages. These need to be tested before panelization.
    [MRCS-Buckeroo.brd, MRCS-Buckeroo.sch]
2023-04-03 Panelized Version1.6
    all works, now panelized 2 up
    [MRCS-Buckeroo V1_5.brd, MRCS-Buckeroo V1_5.sch, MRCS-Buckeroo V1_6-array.brd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]

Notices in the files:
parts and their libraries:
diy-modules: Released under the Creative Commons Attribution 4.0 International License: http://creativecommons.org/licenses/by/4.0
